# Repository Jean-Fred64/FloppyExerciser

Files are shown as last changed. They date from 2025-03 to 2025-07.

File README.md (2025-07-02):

# :floppy_disk: Floppy Drive Exerciser

# Version : GPS 🇯🇵 # Mr JeAn-FReD 🇫🇷

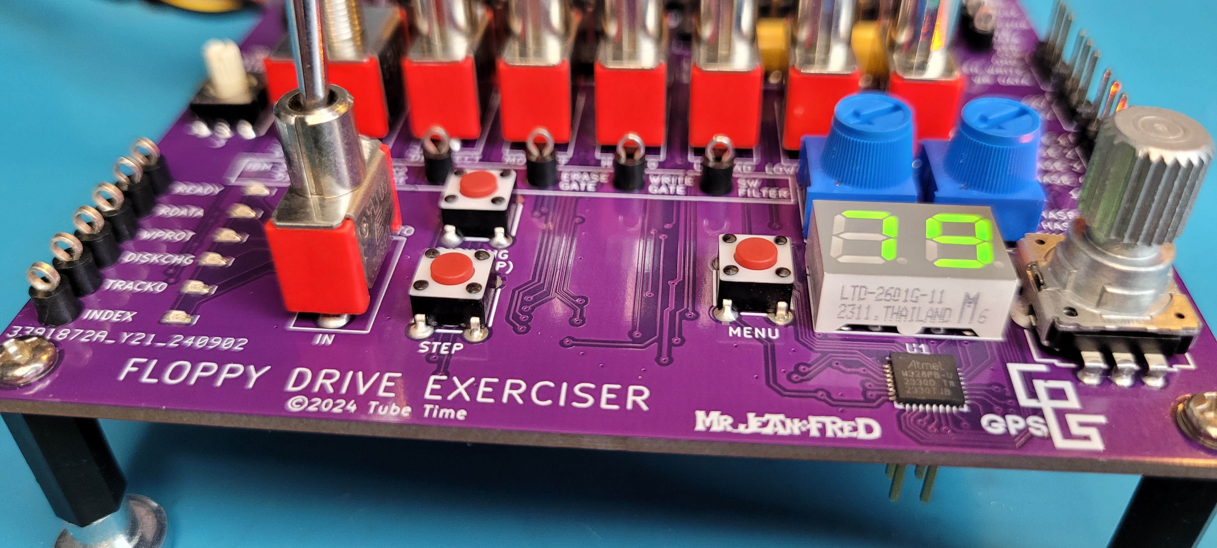
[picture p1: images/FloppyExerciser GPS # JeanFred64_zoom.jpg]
Floppy exerciser circuit board


This board helps test floppy drives of several different types:

* Standard IBM 34-pin drives (3.5" and 5.25")
* IBM PS/2 40-pin drives with embedded power connections
* Shugart 8" floppy drives
* Apple II (original Disk II)
* HP 34-pin drives (as found in many 9122 enclosures)
* HP 26-pin drives (found in older enclosures and machines)
* IBM 31SD and 51TD floppy drives
* Shugart 3.5" (Commodore Amiga) floppy drives with [50 pin to 34 pin adapter](https://github.com/Jean-Fred64/FloppyExerciser/blob/Jean_Fred64/50%20pin%20to%2034%20pin%20Mr%20JEANxFRED/readme.md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)

The board basically breaks out every signal to a control switch, indicator LED, or test point. It's not designed as a flux imaging tool--it's just a simple way to exercise features of a floppy drive.

There is an optional section of the board that is a step controller for the head stepper motor. This controller has an encoder wheel and a small 7-segment display. It will let you select and automatically step to a particular track.

Features include:

* Two potentiometers control step pulse width and step period (speed)
* Generates TG43 signal (Track greater than 43, for variable write current)
* Alignment mode makes it easy to cycle between track 0, middle, and last track
* Supports half tracking (Apple II) and double tracking modes
* Supports direct stepper motor drive through separate header
* Direct stepper drive supports half track, double track, and 1.5x tracking, useful for getting 32 tpi from a 48tpi drive
* Auto track 0 seek function will try to locate track 0

The fab files are [here](https://github.com/Jean-Fred64/FloppyExerciser/tree/Jean_Fred64/Prod).

The schematic is [here](https://github.com/Jean-Fred64/FloppyExerciser/blob/Jean_Fred64/KiCad/FloppyExerciser.pdf).

The bill of materials is [here](https://github.com/Jean-Fred64/FloppyExerciser/blob/Jean_Fred64/BOM)

## Fabrication notes

The board is 100mm x 100mm, 2 layer, standard 1.6mm thickness.

Use toggle switches, not slide switches, otherwise the silkscreen markings will be reveresed.

Use a 3-position switch for the TG43 switch.

Use SIP sockets for RN1 and RN2 so you can swap in different termination resistor values. I usually use 1K.

Be careful about putting any signals on `J2`. If `EN WRITE` gets grounded (the adjacent pin is ground) then it will enable writes on any connected drive, erasing the existing track.

## Connecting Drives

* **Apple II**: Use connector `J12`. Apply -12V, +5V, and +12V to the test points on the left side of the board.
* **PC**: Use connector `J6`. Apply +5V to the test point on the left side of the board. Connect a Molex connector to the floppy drive for power (+5V and sometimes +12V).
* **PS/2**: Use connector `J11`. Apply +5V and +12V to the test points on the left side of the board.
* **Shugart**: Use connector `J9`. Apply +5V to the test point on the left side of the board. Connect the drive to power externally (typically +5V, +24V, and 120VAC).
* **IBM 31SD/51TD**: Use connector `J10`. The 31SD has fewer pins, line it up with pin 1. Apply +5V, -5V, and +24V to the test points on the left side of the board.
* **HP 34-pin**: Use connector `J7`. Apply +5V and +12V to the test points on the left side of the board.
* **HP 26-pin**: Use connector `J8`. Apply +5V to the board and external power to the HP drive.

The board can directly drive an external 4-phase stepper motor. Attach the stepper motor to `J1` and connect either +12V or +24V power to the test points on the left side, and set jumper `J4` to pick the voltage.

## Firmware

### Building the Firmware

The code for the ATMega328PB microcontroller is meant to run without a bootloader and can be built from the command line if you
have installed `avr-gcc` and `avrdude`.

```
make
make fuses
make prog
```

Note that the avrdude command lines in the makefile are hard-coded for the usbtiny programmer. You'll want to change that if you have another type of AVR programmer.

The MCU is new enough that your version of avr-gcc and avrdude may not
support it yet, see [here](https://gist.github.com/goncalor/51e1c8038cc058b4379552477255b4e1) for instructions on how to fix that.

The bottom of the board has a standard 6-pin AVR programming header as a surface mount footprint. Since you only need to program it once, you could plug a header into the programmer's cable and physically push it up against the board, or you could temporarily tack-solder it in place. Or just leave it soldered in place and install standoffs in the corners of the board.

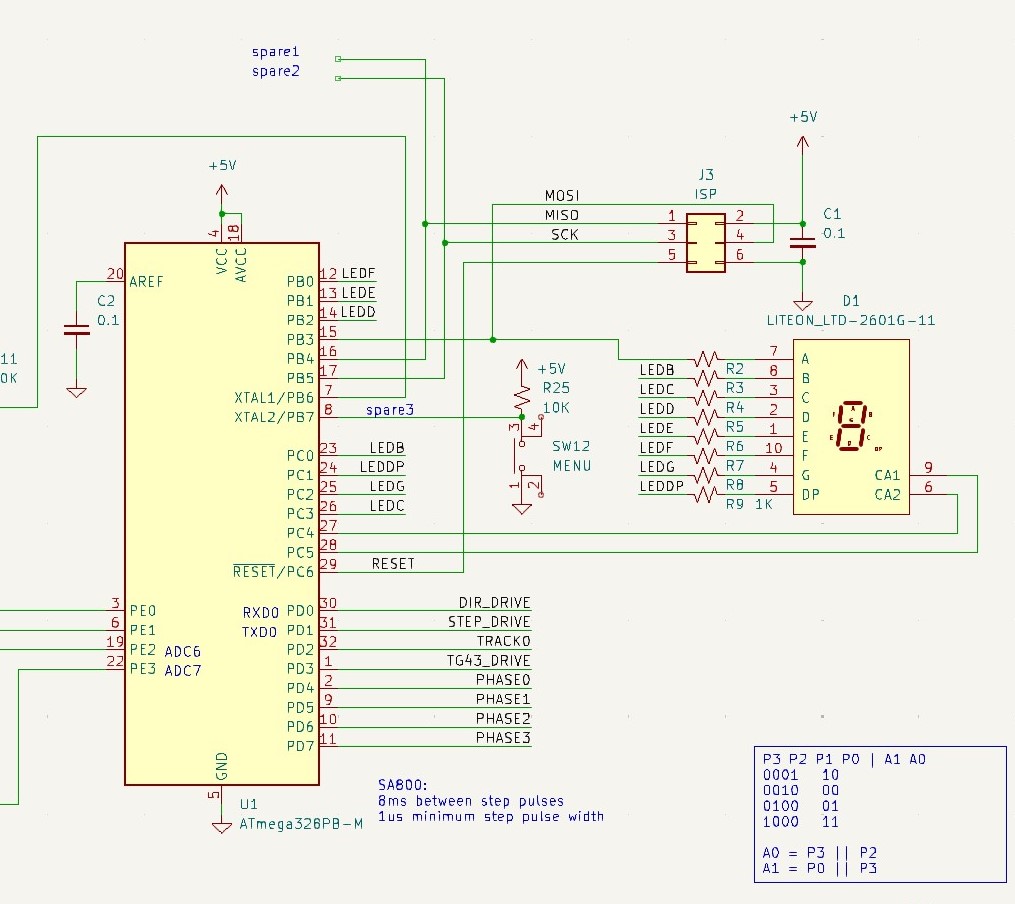
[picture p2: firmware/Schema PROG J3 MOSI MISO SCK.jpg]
schematics J3


### Using the Firmware

On startup, the display will temporarily indicate `HI` and then prompt you for the stepping mode:

* `SS` - single step
* `DS` - double step
* `HS` - half step
* `15` - 1.5x step

Half step mode and 1.5x step are supported on the direct drive stepper motor header and the Apple II header.

Select the mode with the encoder wheel and then push it down to select the option.

The display now indicates the current track. Move the encoder wheel to pick a new track. The display will blink to indicate your desired track. Once you are satisfied with it, push down on the encoder to select that track.

*Tips :*
if you push and hold the button down while turning it, it immediately steps to that track while displaying that track number

For additional functions, you can push the menu button. Menu options are selected with the encoder wheel:

* `HO` - Home to track 0. The controller seeks until TRACK0 asserts or it steps by 80 tracks
* `A8` - Alignment mode for 80 tracks. In this mode, the encoder switches between track 0, track 39, and track 79
* `A7` - Alignment mode for 77 tracks
* `A4` - Alignment mode for 40 tracks
* `35` - Alignment mode for 35 tracks

To exit alignment modes, push the menu button.

The board will control the TG43 (track greater than 43) signal used by 8" drives as long as the switch is set to "AUTO".

* **RATE (RV1)** - rate sets how fast the firmware steps the drive

* **Pulse width (RV2)** - pulse width sets how wide the pulses are that it feeds to the drive, sometimes you have to adjust it for certain drives.

* **STEP (SW2)** - STEP lets you manually step the stepper motor even with no firmware.

* **DIR OUT / AUTO - IN (SW10)** - DIR OUT means step the head to the outside edge direction - AUTO means let the firmware control the direction pin - DIR IN means step in towards the hub.

* **DISKCHG RESET (HP) (SW3)** - DISKCHG RESET is only for certain HP drives that have a flip flop built in for tracking disk changes.

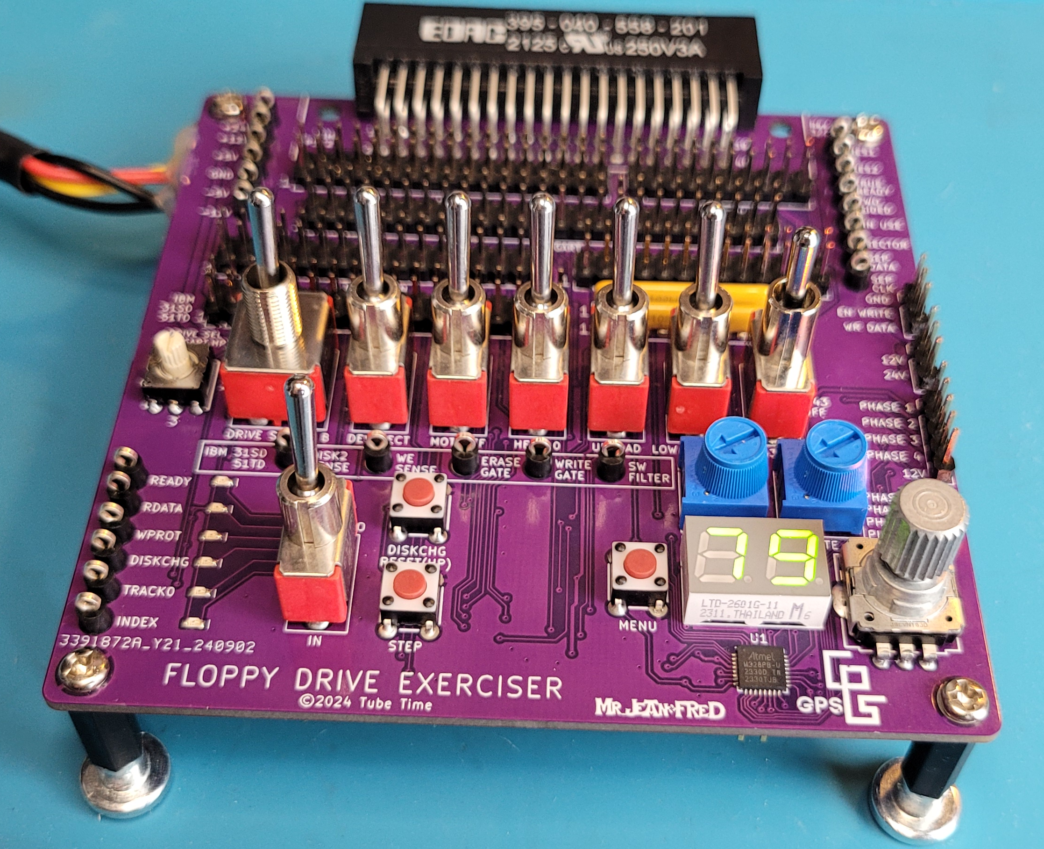
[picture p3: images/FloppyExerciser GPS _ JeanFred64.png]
Floppy exerciser circuit board


## Licensing

This work is licensed under a Creative Commons Attribution-ShareAlike 4.0 International License. See [https://creativecommons.org/licenses/by-sa/4.0/](https://creativecommons.org/licenses/by-sa/4.0/).

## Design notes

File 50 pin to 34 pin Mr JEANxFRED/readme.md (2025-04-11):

# 50 pin to 34 pin adapter for Floppy Drive Exerciser

:construction: Still WORK IN PROGRESS :construction: 

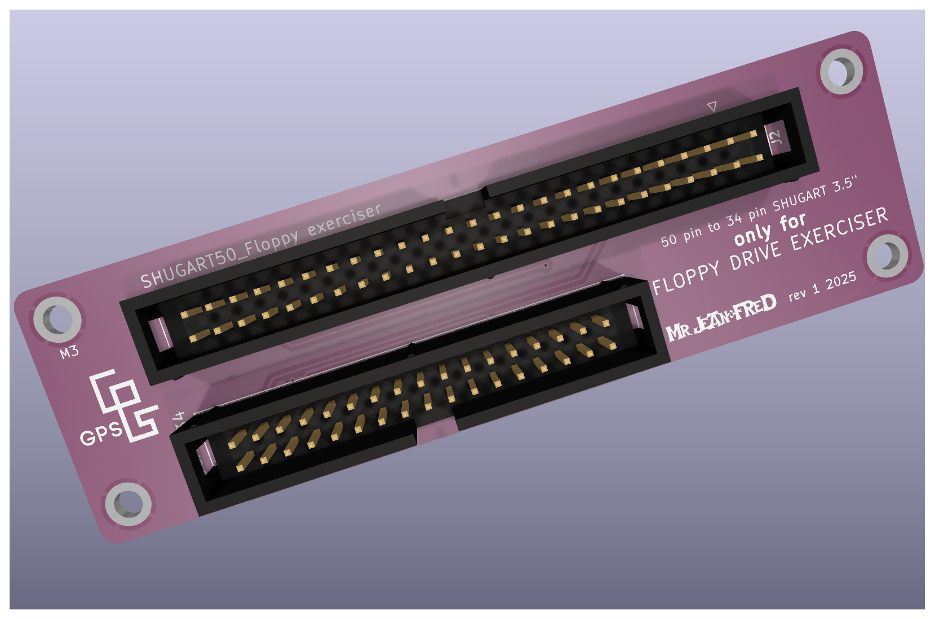
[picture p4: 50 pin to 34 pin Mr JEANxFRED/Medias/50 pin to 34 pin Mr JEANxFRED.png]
50 pin to 34 pin adapter


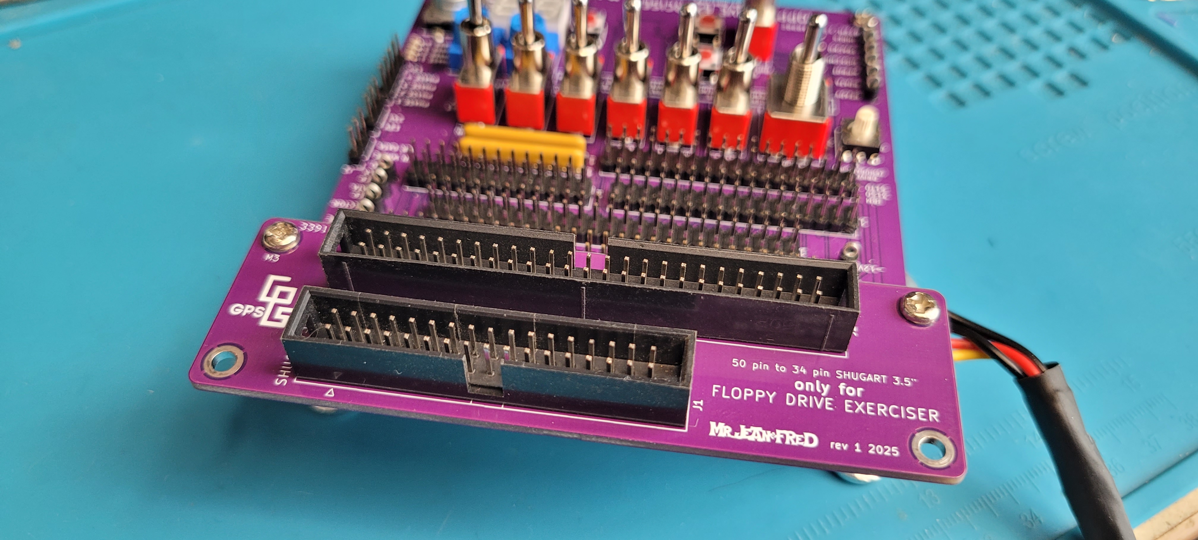
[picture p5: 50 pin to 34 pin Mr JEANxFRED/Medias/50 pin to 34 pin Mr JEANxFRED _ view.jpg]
50 pin to 34 pin adapter _ view


---

To connect a 3.5" SHUGART floppy drive (34 pins) via SHUGART 50 pins port on Floppy Drive Exerciser

---

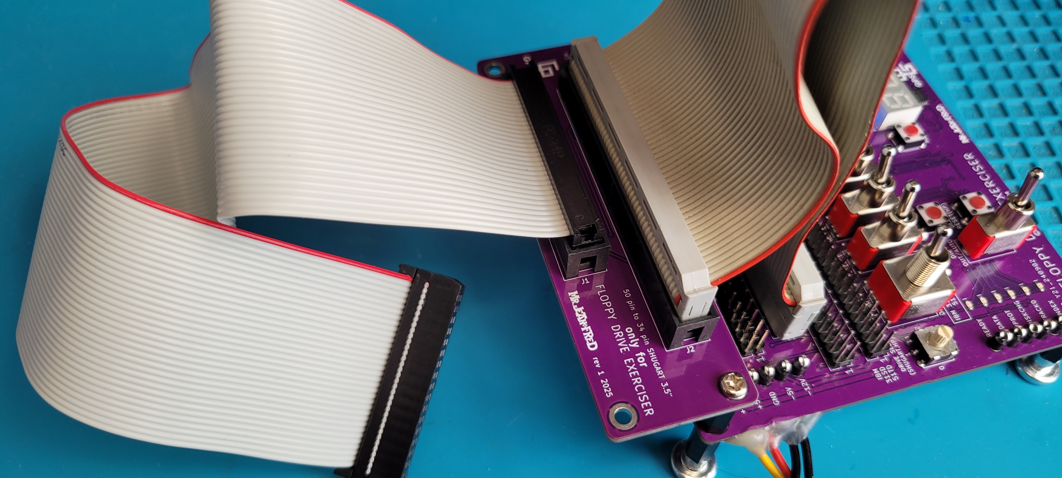
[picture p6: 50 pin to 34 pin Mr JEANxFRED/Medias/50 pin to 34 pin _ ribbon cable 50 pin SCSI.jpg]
50 pin to 34 pin adapter _ SCSI Cable


50 pin SCSI ribbon cable

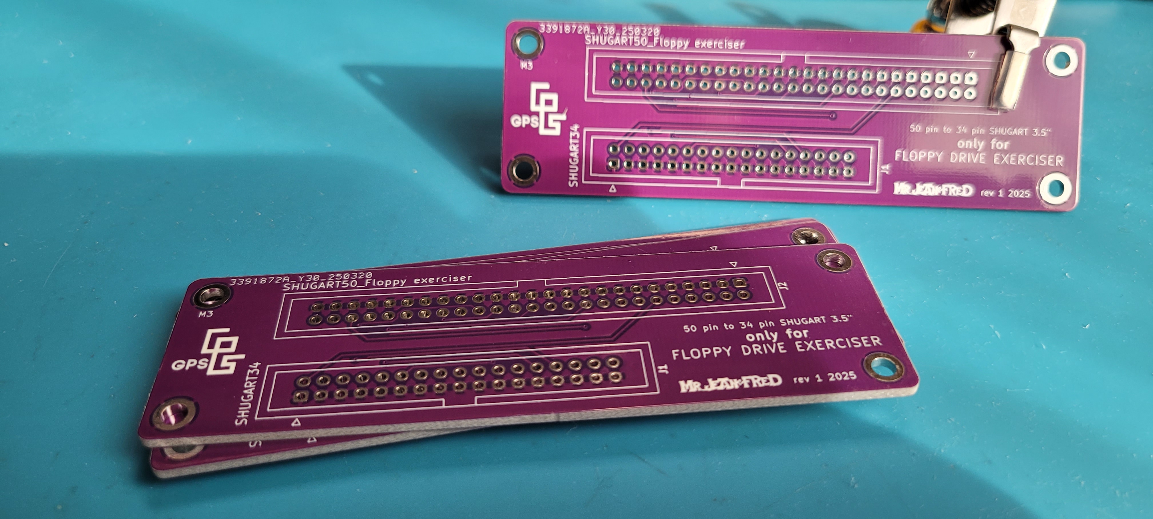
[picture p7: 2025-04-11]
50 pin to 34 pin Mr JEANxFRED/Medias/50 pin to 34 pin _ PCB.jpg

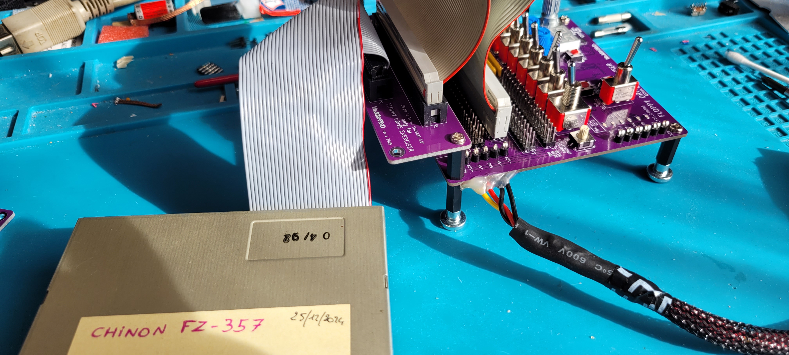
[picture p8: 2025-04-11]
50 pin to 34 pin Mr JEANxFRED/Medias/50 pin to 34 pin _ Chinon SHUGART Amiga.jpg

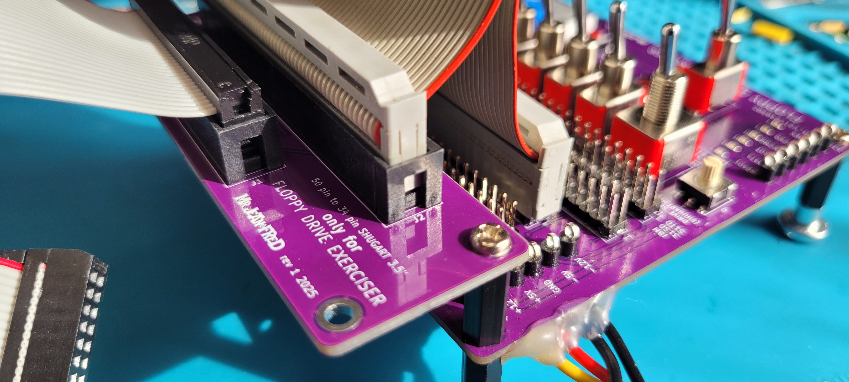
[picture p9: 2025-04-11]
50 pin to 34 pin Mr JEANxFRED/Medias/50 pin to 34 pin Mr JEANxFRED _ zoom.jpg

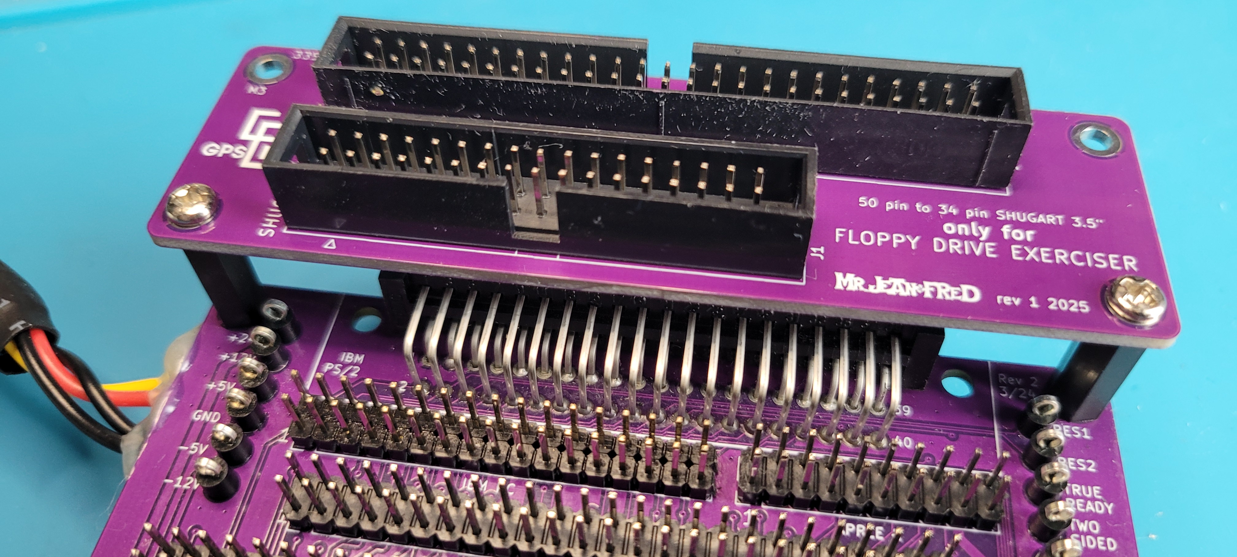
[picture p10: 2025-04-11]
50 pin to 34 pin Mr JEANxFRED/Medias/50 pin to 34 pin _ Front wrong side.jpg

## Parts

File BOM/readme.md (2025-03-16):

Download iBOM.HTML

The bill of materials is [here](https://github.com/Jean-Fred64/FloppyExerciser/blob/Jean_Fred64/BOM/ibom.html)

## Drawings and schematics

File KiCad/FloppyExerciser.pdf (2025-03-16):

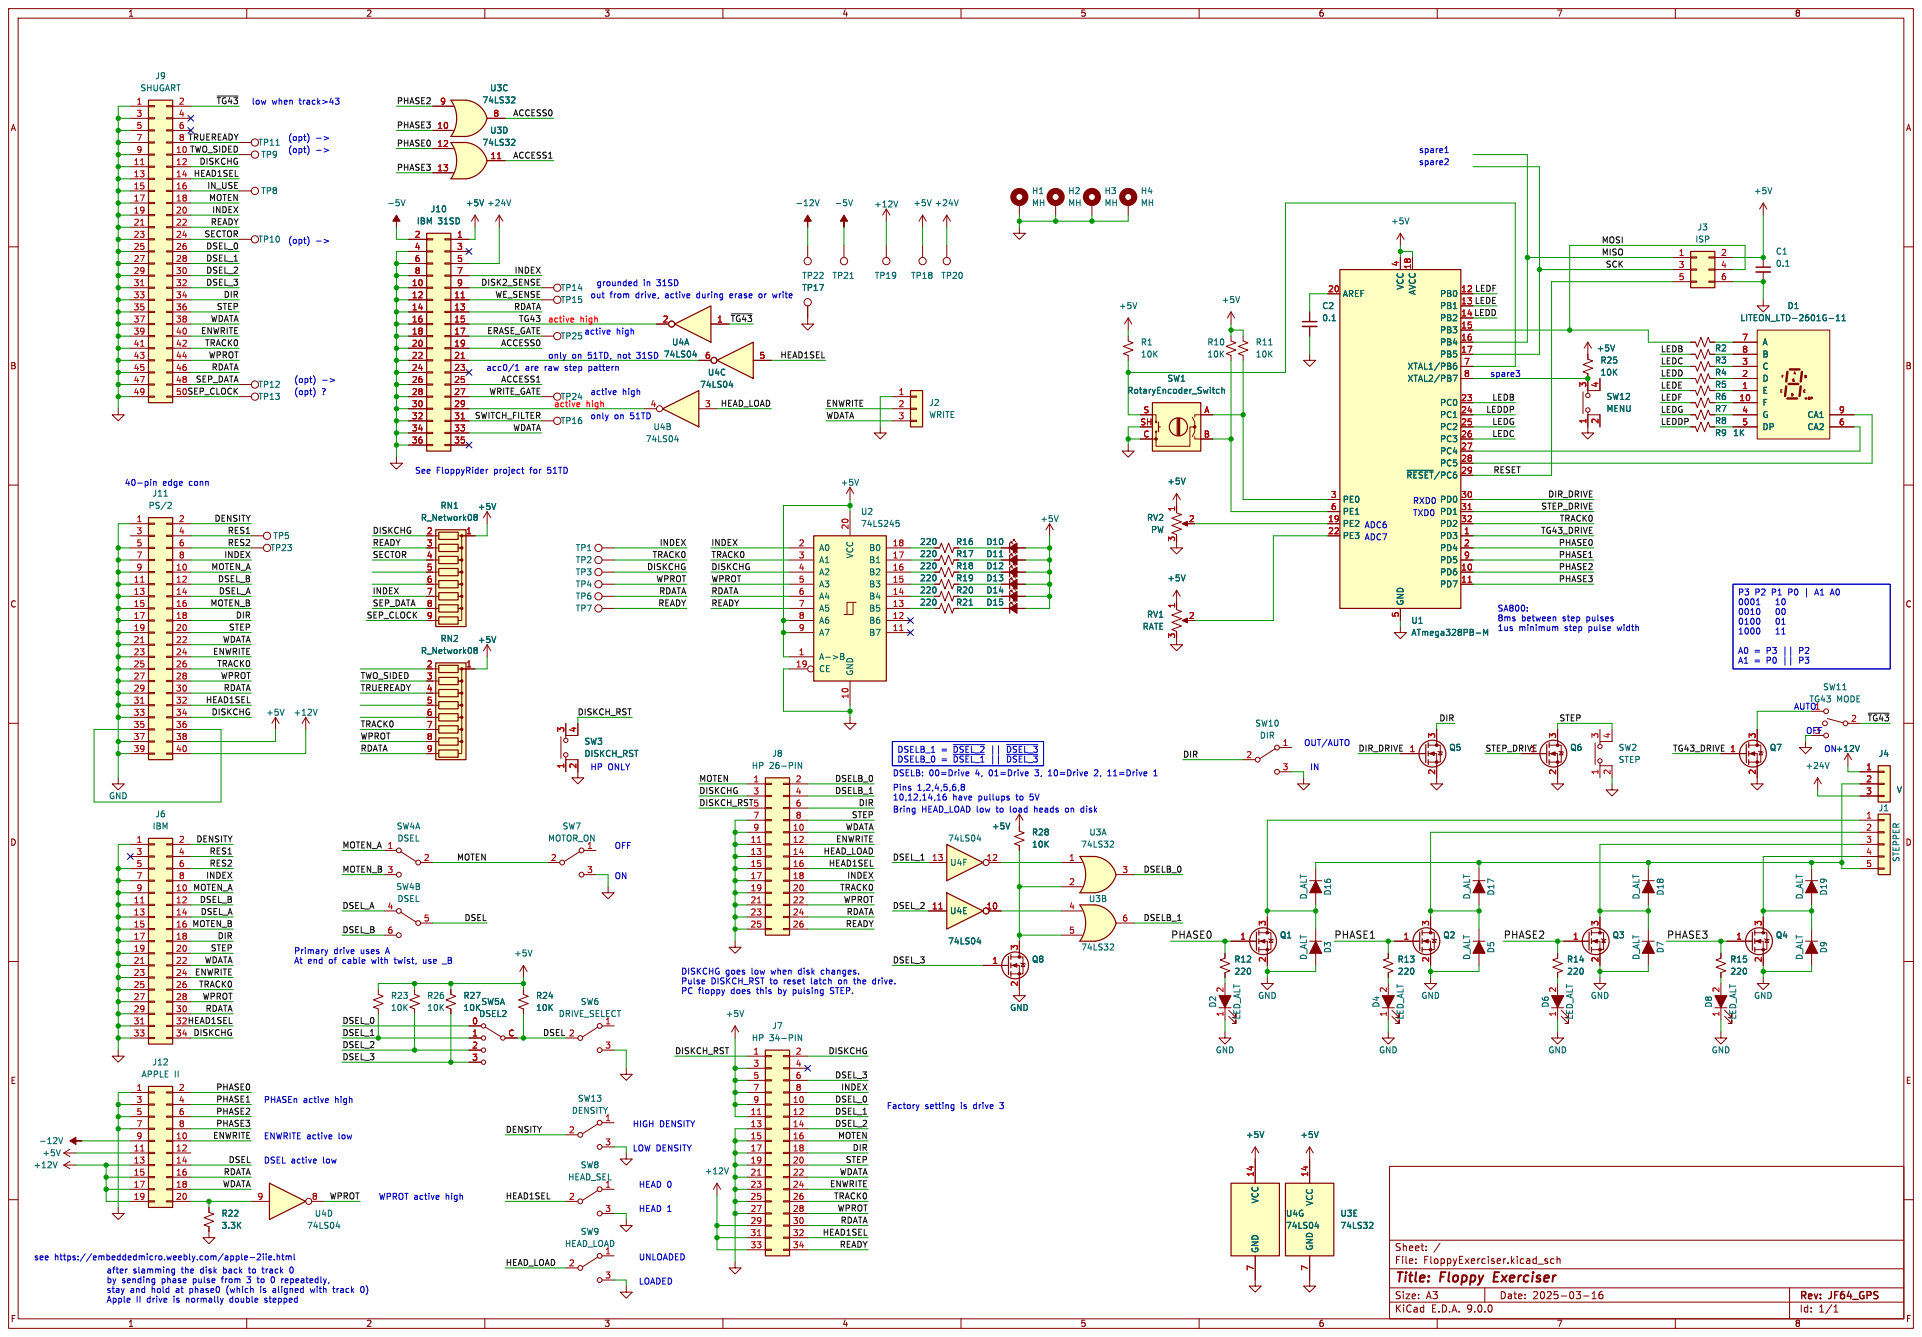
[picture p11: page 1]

grounded in 31SD
out from drive, active during erase or write

Primary drive uses A
At end of cable with twist, use _B

Factory setting is drive 3 DISKCHG goes low when disk changes. Pulse DISKCH_RST to reset latch on the drive. PC floppy does this by pulsing STEP. LOADED

WPROT active high PHASEn active high

see https://embeddedmicro.weebly.com/apple-2iie.html

by sending phase pulse from 3 to 0 repeatedly, stay and hold at phase0 (which is aligned with track 0)

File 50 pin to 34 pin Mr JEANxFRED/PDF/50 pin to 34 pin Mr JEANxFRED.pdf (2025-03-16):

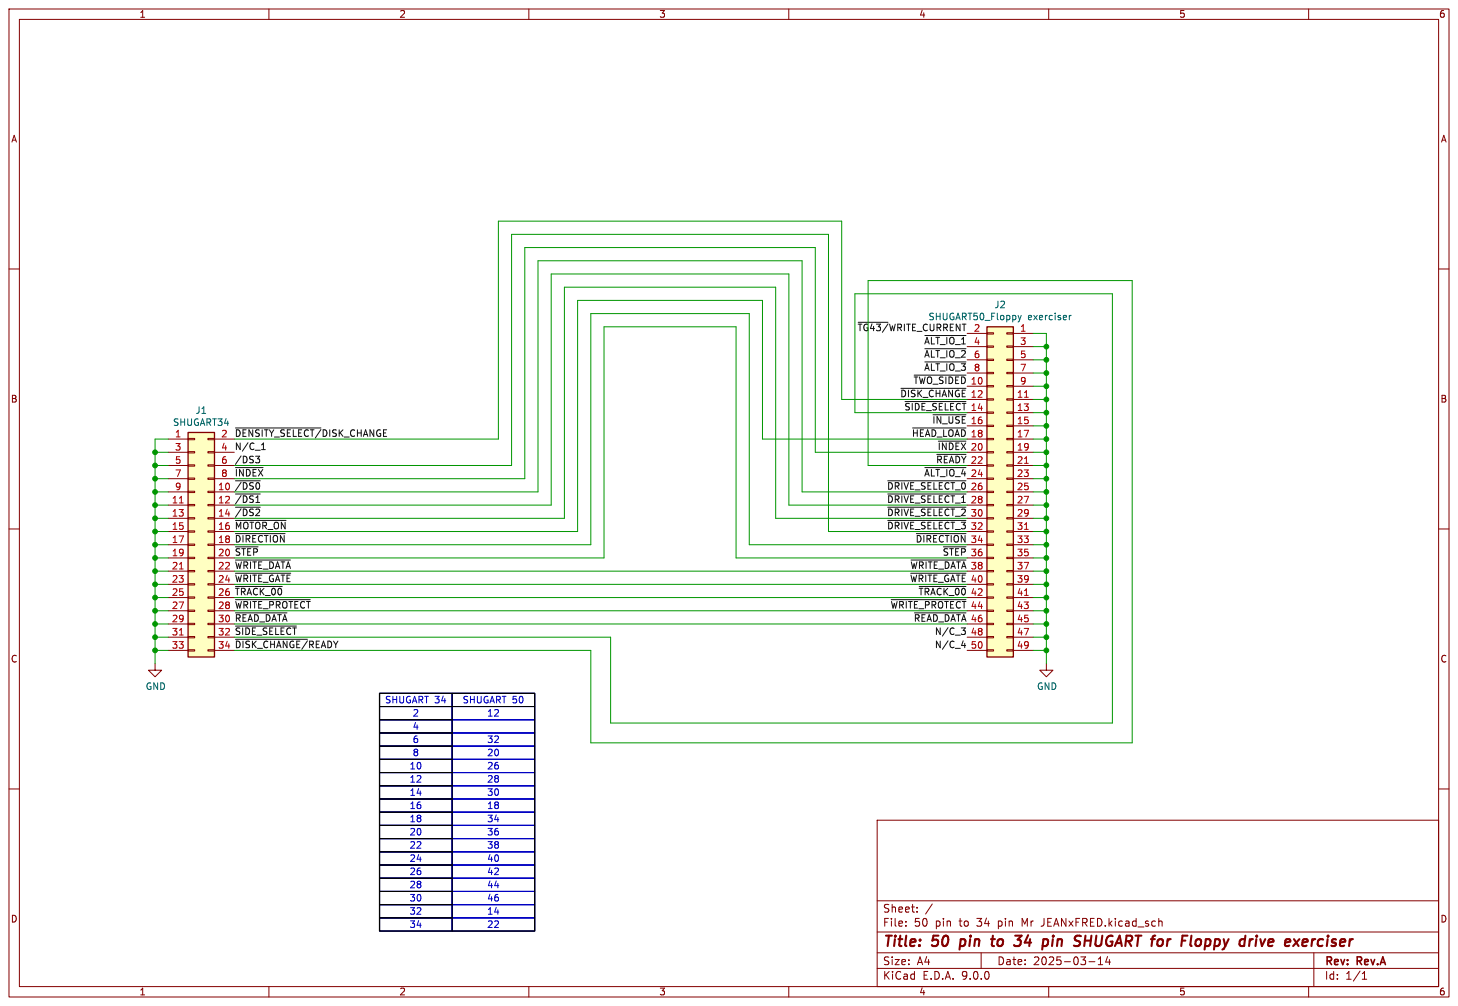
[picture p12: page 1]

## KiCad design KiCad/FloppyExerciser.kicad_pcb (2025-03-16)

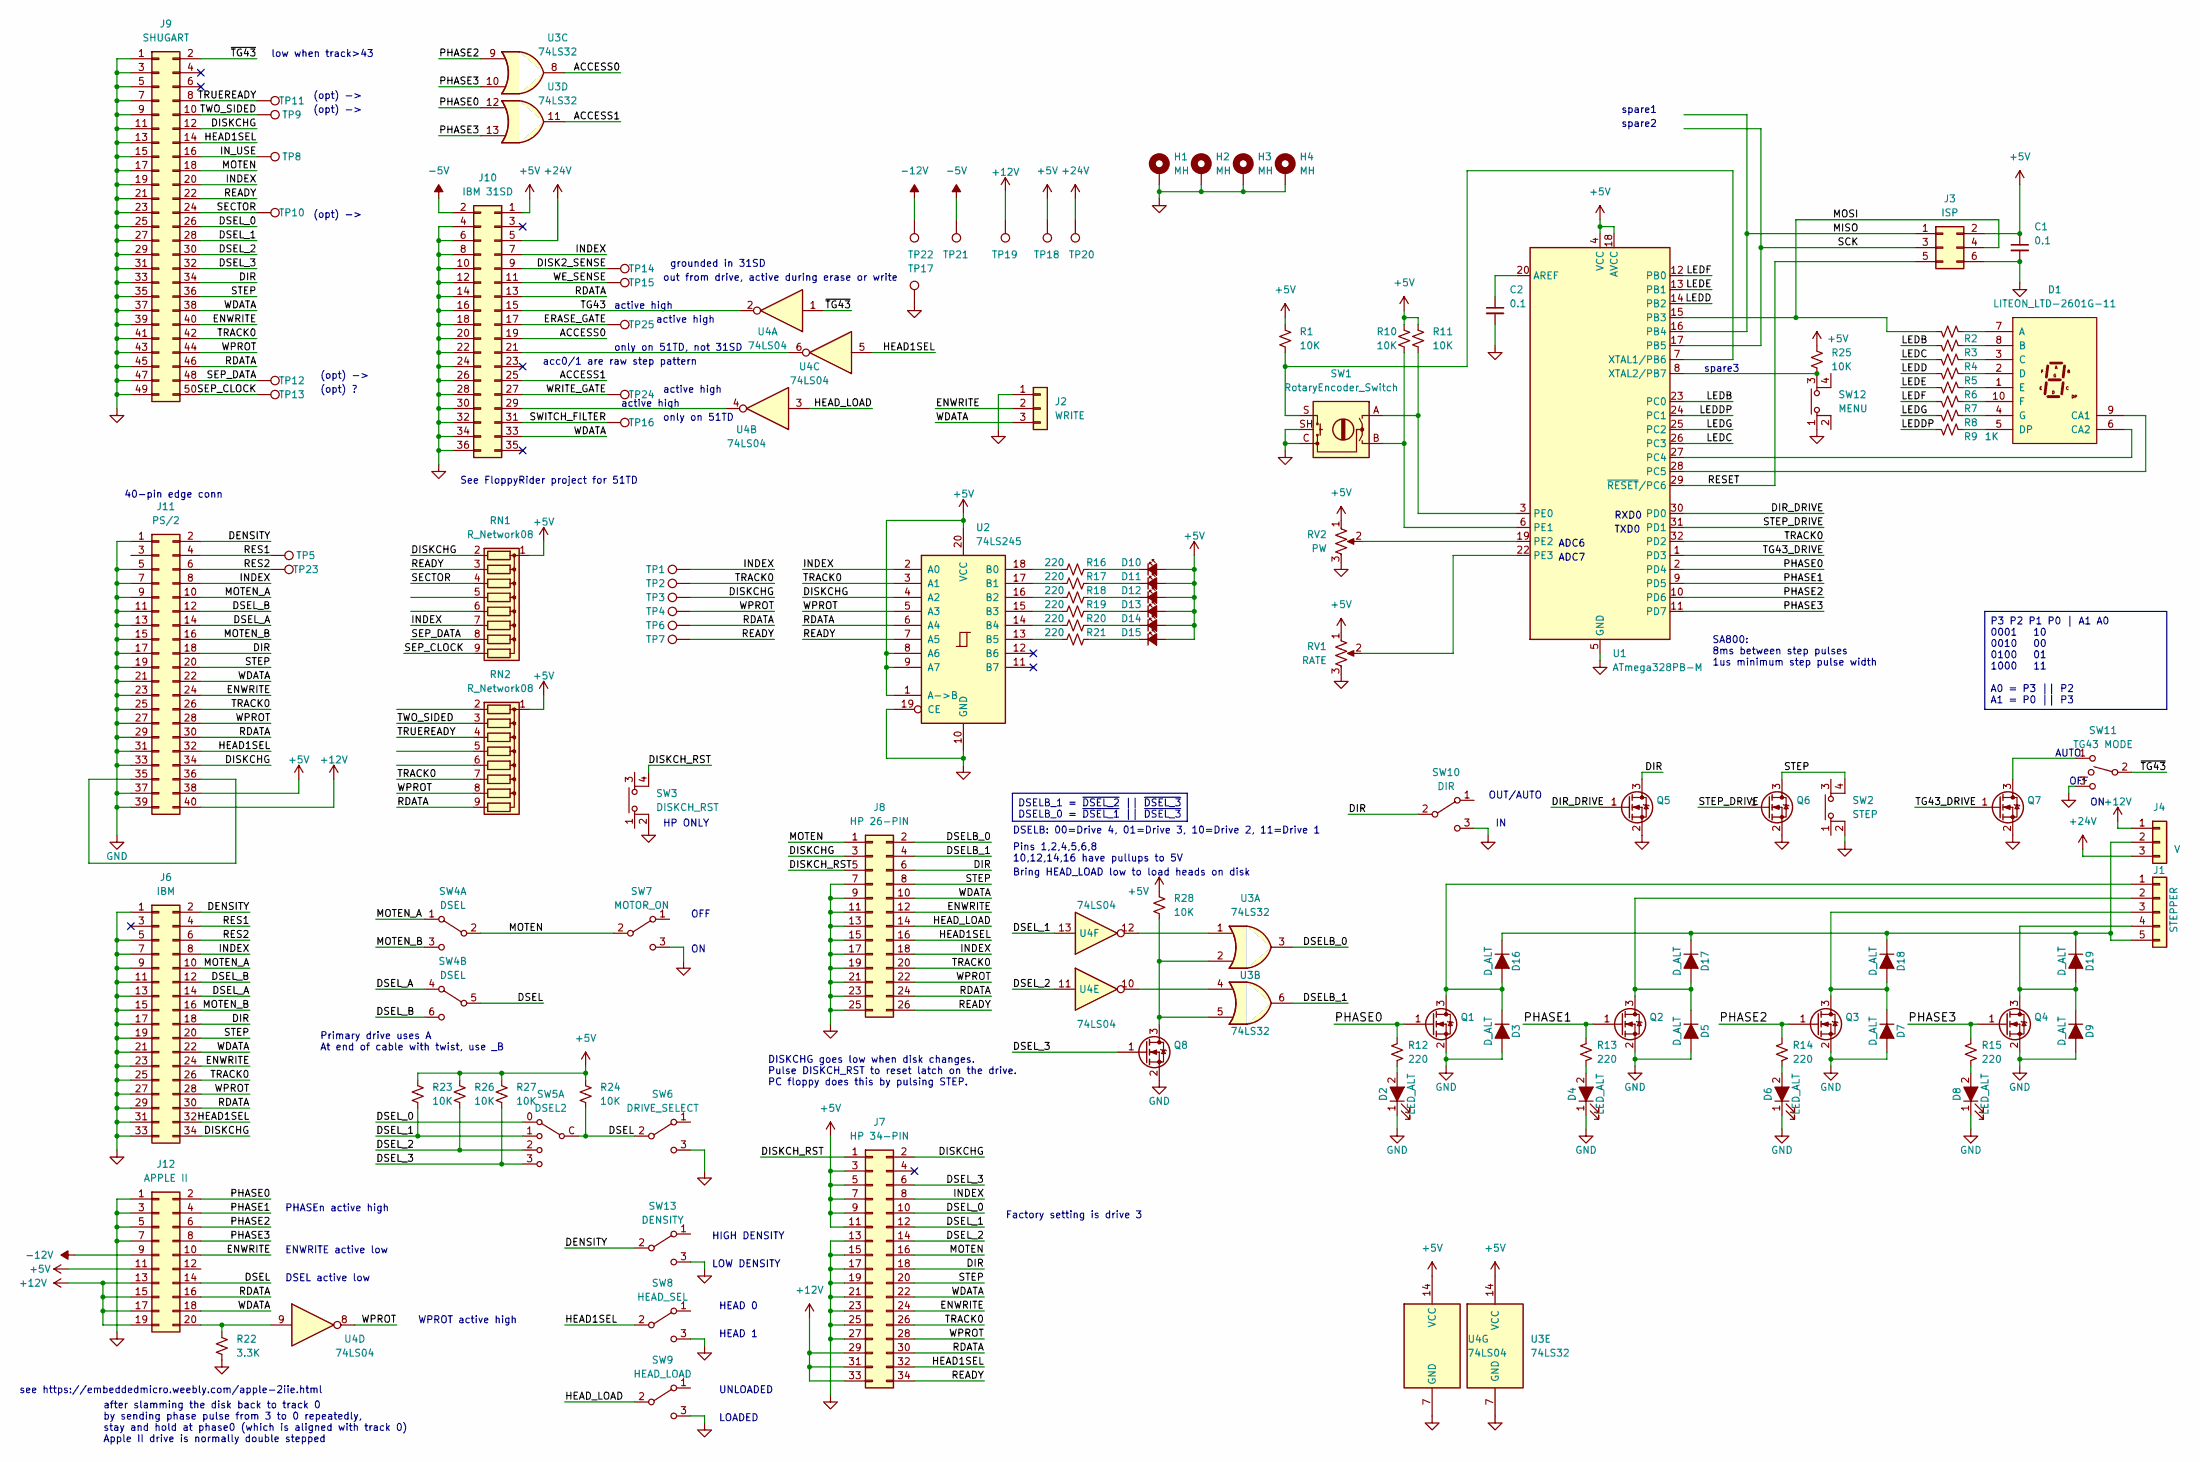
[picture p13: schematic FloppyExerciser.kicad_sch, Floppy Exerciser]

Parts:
C1, C2: 0.1; CAPC1608X100; Digikey 399-C0603C104K4RAC7867CT-ND
D1: LITEON_LTD-2601G-11; LTD-2601G-11; Digikey 160-1922-5-ND
D2, D4, D6, D8: LED_ALT; LEDM1608X50; Digikey 160-1445-1-ND
D3, D5, D7, D9, D16, D17, D18, D19: D_ALT; DIOM5226X210; Digikey ES1B-E3/61TGICT-ND
D10, D11, D12, D13, D14, D15: LED_Small_Filled; LEDM1608X50; Digikey 160-1445-1-ND
H1, H2, H3, H4: MH; MH_125_200
J1: STEPPER; PinHeader_1x05_P2.54mm_Vertical
J2: WRITE; PinHeader_1x03_P2.54mm_Vertical
J3: ISP; PinHeader_2x03_P2.54mm_Vertical_SMD
J4: V; PinHeader_1x03_P2.54mm_Vertical
J6: IBM; PinHeader_2x17_P2.54mm_Vertical
J7: HP 34-PIN; PinHeader_2x17_P2.54mm_Vertical
J8: HP 26-PIN; PinHeader_2x13_P2.54mm_Vertical
J9: SHUGART; PinHeader_2x25_P2.54mm_Vertical
J10: IBM 31SD; PinHeader_2x18_P2.54mm_Vertical
J11: PS/2; EDAC_395-040-559-212; Mouser 587-395-040-558-201
J12: APPLE II; PinHeader_2x10_P2.54mm_Vertical
Q1, Q2, Q3, Q4, Q5, Q6, Q7, Q8: N-Channel 40 V 4.3A (Ta), 5.6A (Tc) 1.25W (Ta), 2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; SOT95P230X117-3; Mouser 78-SI2318CDS-T1-BE3
R1, R10, R11, R23, R24, R25, R26, R27, R28: 10K; RESC1608X55; Digikey 541-2204-1-ND
R2, R3, R4, R5, R6, R7, R8, R9: 1K; RESC1608X55; Digikey 541-1.00KHCT-ND
R12, R13, R14, R15, R16, R17, R18, R19, R20, R21: 220; RESC1608X55; Digikey 541-220HCT-ND
R22: 3.3K; RESC1608X55; Digikey 541-3.30KHCT-ND
RN1, RN2: R_Network08; R_Array_SIP9; Digikey 4609X-101-102LF-ND
RV1: RATE; BOURNS_3386_VERT_UNIVERSAL; Digikey 3386F-1-202TLF
RV2: PW; BOURNS_3386_VERT_UNIVERSAL; Digikey 3386F-1-202TLF
SW1: RotaryEncoder_Switch; PANASONIC_EVEY; Mouser 667-EVE-YBCAJO16B
SW2: STEP; ESWITCH_TL1105; Digikey EG1828-ND
SW3: DISKCH_RST; ESWITCH_TL1105; Digikey EG1828-ND
SW4: DSEL; SW_DPDT; Digikey 100DP1T1B1M2QE
SW5: DSEL2; CTS_220AD_04; Digikey CT3098-ND
SW6: DRIVE_SELECT; SW_SPDT; Mouser 612-100-A1421
SW7: MOTOR_ON; SW_SPDT; Mouser 612-100-A1421
SW8: HEAD_SEL; SW_SPDT; Mouser 612-100-A1421
SW9: HEAD_LOAD; SW_SPDT; Mouser 612-100-A1421
SW10: DIR; SW_SPDT; Mouser 612-100-A1421
SW11: TG43 MODE; SW_SPDT; Digikey 141-100DP6T3B4M2QE-ND
SW12: MENU; ESWITCH_TL1105; Digikey EG1828-ND
SW13: DENSITY; SW_SPDT; Mouser 612-100-A1421
TP1, TP2, TP3, TP4, TP5, TP6, TP7, TP8, TP9, TP10, TP11, TP12, TP13, TP14, TP15, TP16, TP17, TP18, TP19, TP20, TP21, TP22, TP23, TP24, TP25: TestPoint; TP_KEYSTONE_5005_9; Digikey 36-5006-ND
U1: ATmega328PB-M; QFN-32-1EP_5x5mm_P0.5mm_EP3.1x3.1mm; Digikey ATMEGA328PB-MU-ND
U2: 74LS245; SOP127P1065X265-20; Mouser 595-SN74LS245DW
U3: 74LS32; SOP127P620X175-14; Mouser 595-SN74LS32DR
U4: 74LS04; SOP127P620X175-14; Mouser 595-SN74LS04D

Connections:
+5V: C1.1, D10.2 (A), D11.2 (A), D12.2 (A), D13.2 (A), D14.2 (A), D15.2 (A), J3.2, J7.3, J7.5, J7.7, J7.9, J7.11, J10.1, J11.38, J12.11, R1.1, R10.1, R11.1, R23.1, R24.1, R25.1, R26.1, R27.1, R28.1, RN1.1 (common), RN2.1 (common), RV1.1, RV2.1, TP18.1, U1.4 (VCC), U1.18 (AVCC), U2.1 (A->B), U2.8 (A6), U2.9 (A7), U2.20 (VCC), U3.14 (VCC), U4.14 (VCC)
+12V: J4.1, J7.29, J7.31, J7.33, J11.40, J12.13, J12.15, J12.17, J12.19, TP19.1
+24V: J4.3, J10.5, TP20.1
-5V: J10.2, TP21.1
-12V: J12.9, TP22.1
/ACCESS0: J10.19, U3.8
/ACCESS1: J10.25, U3.11
/DENSITY: J6.2, J11.2, SW13.2 (B)
/DIR: J6.18, J7.18, J8.6, J9.34, J11.18, Q5.3 (D), SW10.2 (B)
/DIR_DRIVE: Q5.1 (G), U1.30 (PD0)
/DISK2_SENSE: J10.9, TP14.1
/DISKCHG: J6.34, J7.2, J8.3, J9.12, J11.34, RN1.2 (R1), TP3.1, U2.4 (A2)
/DISKCH_RST: J7.1, J8.5, SW3.4
/DSEL: J12.14, R24.2, SW4.5 (B), SW5.C, SW6.2 (B)
/DSELB_0: J8.2, U3.3
/DSELB_1: J8.4, U3.6
/DSEL_0: J7.10, J9.26, SW5.0
/DSEL_1: J7.12, J9.28, R23.2, SW5.1, U4.13
/DSEL_2: J7.14, J9.30, R26.2, SW5.2, U4.11
/DSEL_3: J7.6, J9.32, Q8.1 (G), R27.2, SW5.3
/DSEL_A: J6.14, J11.14, SW4.4 (A)
/DSEL_B: J6.12, J11.12, SW4.6 (C)
/ENWRITE: J2.2, J6.24, J7.24, J8.12, J9.40, J11.24, J12.10
/ERASE_GATE: J10.17, TP25.1
/HEAD1SEL: J6.32, J7.32, J8.16, J9.14, J11.32, SW8.2 (B), U4.5
/HEAD_LOAD: J8.14, SW9.2 (B), U4.3
/INDEX: J6.8, J7.8, J8.18, J9.20, J10.7, J11.8, RN1.7 (R6), TP1.1, U2.2 (A0)
/IN_USE: J9.16, TP8.1
/LEDB: R3.1, U1.23 (PC0)
/LEDC: R4.1, U1.26 (PC3)
/LEDD: R5.1, U1.14 (PB2)
/LEDDP: R9.1, U1.24 (PC1)
/LEDE: R6.1, U1.13 (PB1)
/LEDF: R7.1, U1.12 (PB0)
/LEDG: R8.1, U1.25 (PC2)
/MISO: J3.1, U1.16 (PB4)
/MOSI: J3.4, R2.1, U1.15 (PB3)
/MOTEN: J7.16, J8.1, J9.18, SW4.2 (B), SW7.2 (B)
/MOTEN_A: J6.10, J11.10, SW4.1 (A)
/MOTEN_B: J6.16, J11.16, SW4.3 (C)
/PHASE0: J12.2, Q1.1 (G), R12.2, U1.2 (PD4), U3.12
/PHASE1: J12.4, Q2.1 (G), R13.2, U1.9 (PD5)
/PHASE2: J12.6, Q3.1 (G), R14.2, U1.10 (PD6), U3.9
/PHASE3: J12.8, Q4.1 (G), R15.2, U1.11 (PD7), U3.10, U3.13
/RDATA: J6.30, J7.30, J8.24, J9.46, J10.13, J11.30, J12.16, RN2.9 (R8), TP6.1, U2.6 (A4)
/READY: J7.34, J8.26, J9.22, RN1.3 (R2), TP7.1, U2.7 (A5)
/RES1: J6.4, J11.4, TP5.1
/RES2: J6.6, J11.6, TP23.1
/RESET: J3.5, U1.29 (~RESET/PC6)
/SCK: J3.3, U1.17 (PB5)
/SECTOR: J9.24, RN1.4 (R3), TP10.1
/SEP_CLOCK: J9.50, RN1.9 (R8), TP13.1
/SEP_DATA: J9.48, RN1.8 (R7), TP12.1
/STEP: J6.20, J7.20, J8.8, J9.36, J11.20, Q6.3 (D), SW2.4
/STEP_DRIVE: Q6.1 (G), U1.31 (PD1)
/SWITCH_FILTER: J10.31, TP16.1
/TG43: J10.15, U4.2
/TG43_DRIVE: Q7.1 (G), U1.1 (PD3)
/TRACK0: J6.26, J7.26, J8.20, J9.42, J11.26, RN2.7 (R6), TP2.1, U1.32 (PD2), U2.3 (A1)
/TRUEREADY: J9.8, RN2.4 (R3), TP11.1
/TWO_SIDED: J9.10, RN2.3 (R2), TP9.1
/WDATA: J2.3, J6.22, J7.22, J8.10, J9.38, J10.33, J11.22, J12.18
/WE_SENSE: J10.11, TP15.1
/WPROT: J6.28, J7.28, J8.22, J9.44, J11.28, RN2.8 (R7), TP4.1, U2.5 (A3), U4.8
/WRITE_GATE: J10.27, TP24.1
/~TG43: J9.2, SW11.2, U4.1
GND: C1.2, C2.2, D2.1 (K), D3.2 (A), D4.1 (K), D5.2 (A), D6.1 (K), D7.2 (A), D8.1 (K), D9.2 (A), H1.1, H2.1, H3.1, H4.1, J2.1, J3.6, J6.1, J6.5, J6.7, J6.9, J6.11, J6.13, J6.15, J6.17, J6.19, J6.21, J6.23, J6.25, J6.27, J6.29, J6.31, J6.33, J7.13, J7.15, J7.17, J7.19, J7.21, J7.23, J7.25, J7.27, J8.7, J8.9, J8.11, J8.13, J8.15, J8.17, J8.19, J8.21, J8.23, J8.25, J9.1, J9.3, J9.5, J9.7, J9.9, J9.11, J9.13, J9.15, J9.17, J9.19, J9.21, J9.23, J9.25, J9.27, J9.29, J9.31, J9.33, J9.35, J9.37, J9.39, J9.41, J9.43, J9.45, J9.47, J9.49, J10.4, J10.6, J10.8, J10.10, J10.12, J10.14, J10.16, J10.18, J10.20, J10.22, J10.24, J10.26, J10.28, J10.30, J10.32, J10.34, J10.36, J11.1, J11.5, J11.7, J11.9, J11.11, J11.13, J11.15, J11.17, J11.19, J11.21, J11.23, J11.25, J11.27, J11.29, J11.31, J11.33, J11.37, J11.39, J12.1, J12.3, J12.5, J12.7, Q1.2 (S), Q2.2 (S), Q3.2 (S), Q4.2 (S), Q5.2 (S), Q6.2 (S), Q7.2 (S), Q8.2 (S), R22.2, RV1.3, RV2.3, SW1.C, SW1.SH, SW2.2, SW3.2, SW6.3 (C), SW7.3 (C), SW8.3 (C), SW9.3 (C), SW10.3 (C), SW11.3, SW12.1, SW13.3 (C), TP17.1, U1.5 (GND), U1.21 (GND), U1.33 (GND), U2.10 (GND), U2.19 (CE), U3.7 (GND), U4.7 (GND)
unnamed: D1.7 (A), R2.2
unnamed: D1.8 (B), R3.2
unnamed: D1.3 (C), R4.2
unnamed: D1.9 (CA1), U1.28 (PC5)
unnamed: D1.6 (CA2), U1.27 (PC4)
unnamed: D1.2 (D), R5.2
unnamed: D1.5 (DP), R9.2
unnamed: D1.1 (E), R6.2
unnamed: D1.10 (F), R7.2
unnamed: D1.4 (G), R8.2
unnamed: D2.2 (A), R12.1
unnamed: D4.2 (A), R13.1
unnamed: D6.2 (A), R14.1
unnamed: D8.2 (A), R15.1
unnamed: D10.1 (K), R16.2
unnamed: D11.1 (K), R17.2
unnamed: D12.1 (K), R18.2
unnamed: D13.1 (K), R19.2
unnamed: D14.1 (K), R20.2
unnamed: D15.1 (K), R21.2
unnamed: D3.1 (K), D16.2 (A), J1.1, Q1.3 (D)
unnamed: D16.1 (K), D17.1 (K), D18.1 (K), D19.1 (K), J1.5, J4.2
unnamed: D5.1 (K), D17.2 (A), J1.2, Q2.3 (D)
unnamed: D7.1 (K), D18.2 (A), J1.3, Q3.3 (D)
unnamed: D9.1 (K), D19.2 (A), J1.4, Q4.3 (D)
unnamed: J10.21, U4.6
unnamed: J10.29, U4.4
unnamed: J11.35, J11.36
unnamed: J12.20, R22.1, U4.9
unnamed: Q7.3 (D), SW11.1
unnamed: Q8.3 (D), R28.2, U3.2, U3.5
unnamed: C2.1, U1.20 (AREF)
unnamed: R11.2, SW1.A, U1.3 (PE0)
unnamed: R10.2, SW1.B, U1.6 (PE1)
unnamed: RV2.2, U1.19 (PE2)
unnamed: RV1.2, U1.22 (PE3)
unnamed: R1.2, SW1.S, U1.7 (XTAL1/PB6)
unnamed: R25.2, SW12.3, U1.8 (XTAL2/PB7)
unnamed: R16.1, U2.18 (B0)
unnamed: R17.1, U2.17 (B1)
unnamed: R18.1, U2.16 (B2)
unnamed: R19.1, U2.15 (B3)
unnamed: R20.1, U2.14 (B4)
unnamed: R21.1, U2.13 (B5)
unnamed: U3.1, U4.12
unnamed: U3.4, U4.10

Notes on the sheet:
WPROT active high
low when track>43
OUT/AUTO
active high
DISKCHG goes low when disk changes. Pulse DISKCH_RST to reset latch on the drive. PC floppy does this by pulsing STEP.
(opt) ->
ENWRITE active low
DSELB: 00=Drive 4, 01=Drive 3, 10=Drive 2, 11=Drive 1
spare3
AUTO
OFF
PHASEn active high
out from drive, active during erase or write
HIGH DENSITY
Factory setting is drive 3
LOADED
grounded in 31SD
Primary drive uses A At end of cable with twist, use _B
See FloppyRider project for 51TD
after slamming the disk back to track 0 by sending phase pulse from 3 to 0 repeatedly, stay and hold at phase0 (which is aligned with track 0) Apple II drive is normally double stepped
TXD0
HEAD 0
Pins 1,2,4,5,6,8 10,12,14,16 have pullups to 5V
HP ONLY
(opt) ?
spare2
UNLOADED
only on 51TD, not 31SD
ADC7
HEAD 1
ADC6
Bring HEAD_LOAD low to load heads on disk
DSEL active low
see https://embeddedmicro.weebly.com/apple-2iie.html
RXD0
acc0/1 are raw step pattern
spare1
LOW DENSITY
SA800: 8ms between step pulses 1us minimum step pulse width
only on 51TD

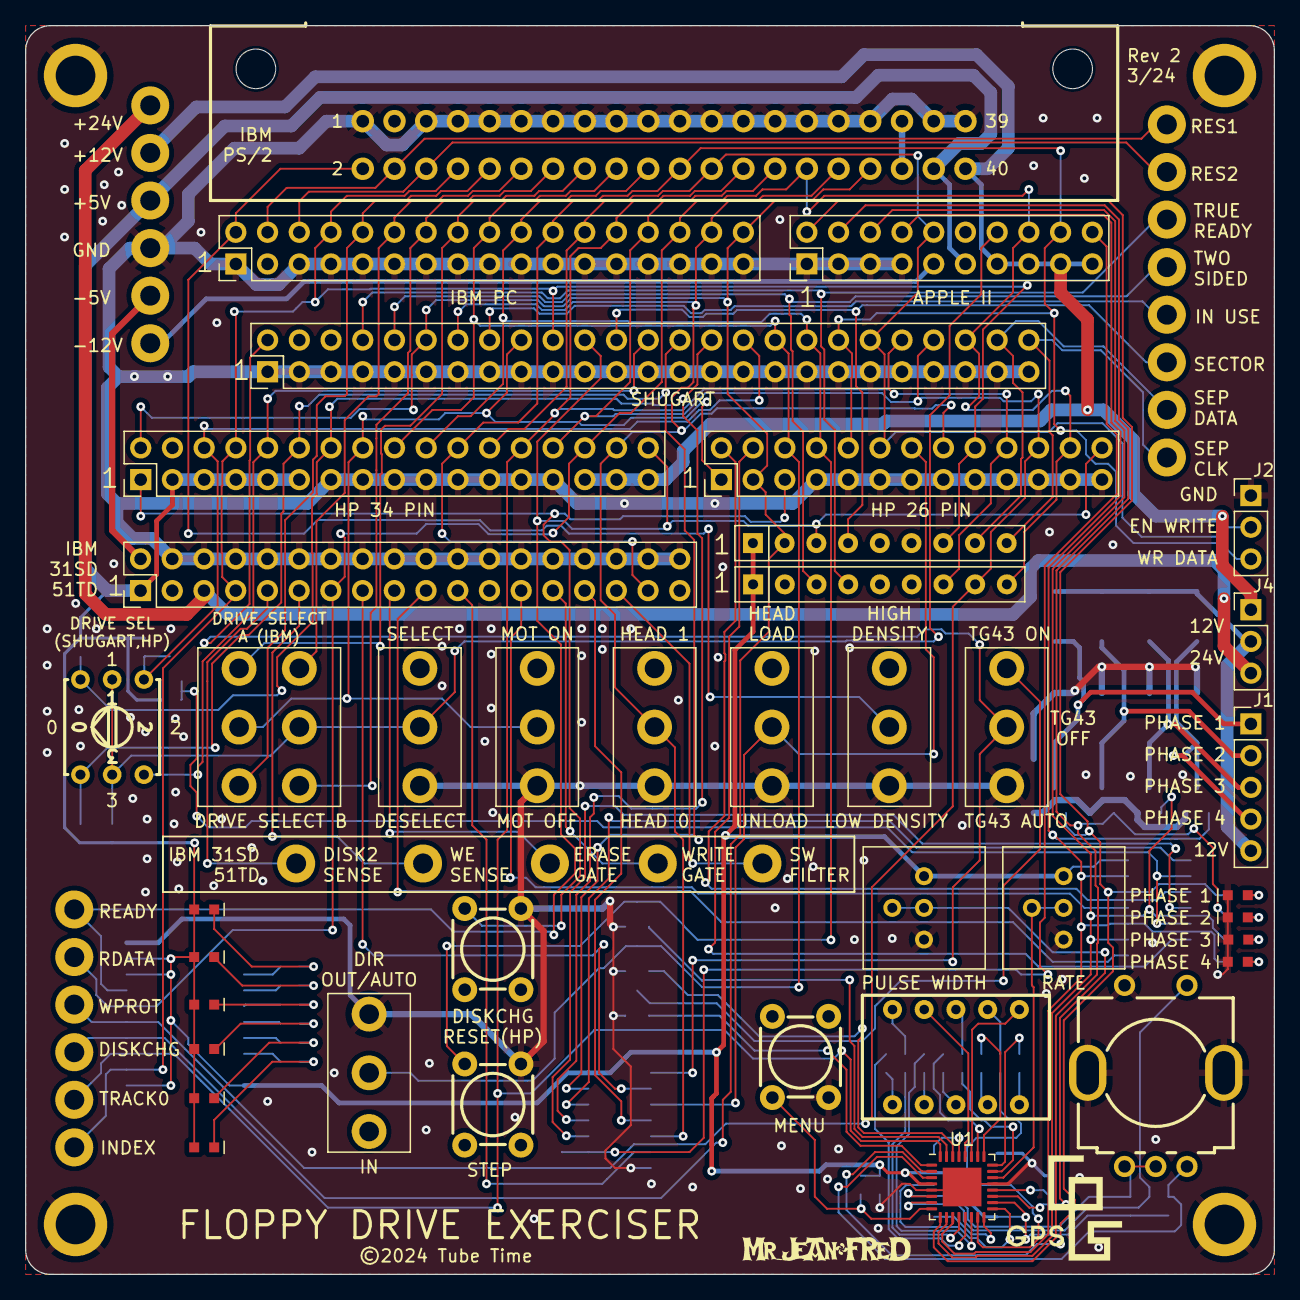
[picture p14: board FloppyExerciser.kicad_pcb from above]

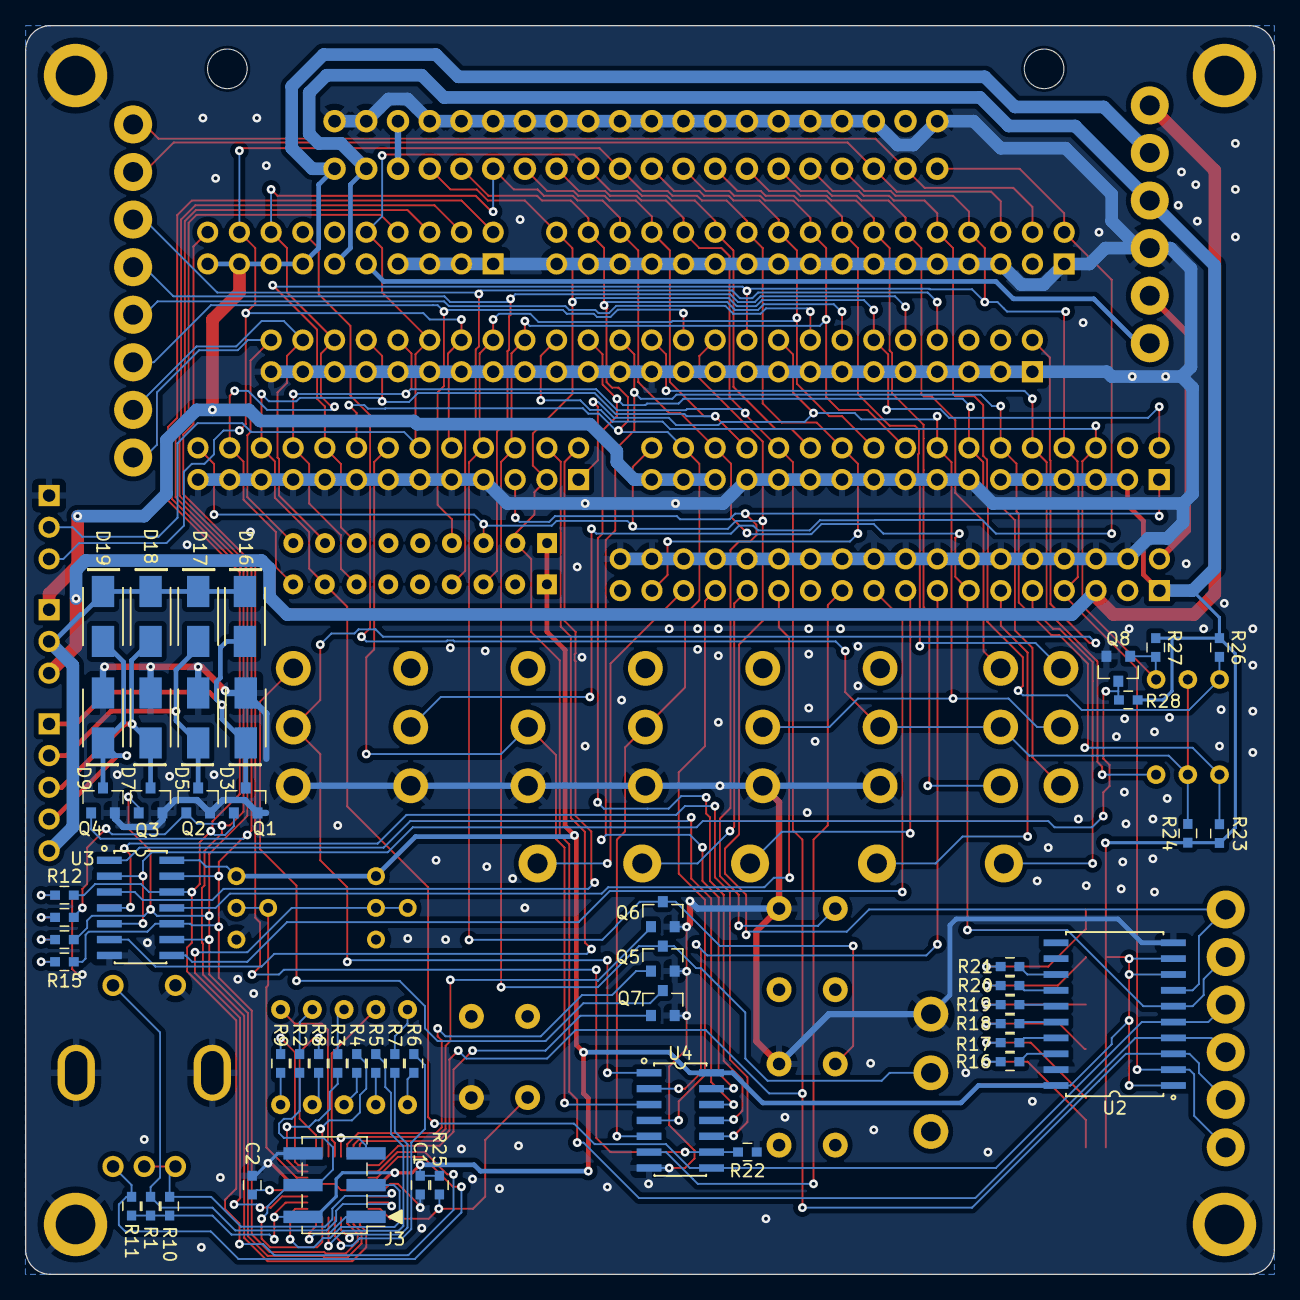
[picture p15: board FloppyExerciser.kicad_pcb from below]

Board: 2 copper layers, 100.0 x 100.0 mm, 118 parts (50 on the bottom side), 113 nets.

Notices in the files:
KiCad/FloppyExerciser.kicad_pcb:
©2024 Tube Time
